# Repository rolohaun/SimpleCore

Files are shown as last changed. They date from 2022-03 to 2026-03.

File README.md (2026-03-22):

> [!WARNING]
> # 🚨 OUT OF DATE 🚨
> **This repository is out of date!** The updated printer is here: [SimpleCore on Printables](https://www.printables.com/model/1473500-simplecore)

---

# SimpleCore MK1
This is the official MK1 SimpleCore Github!

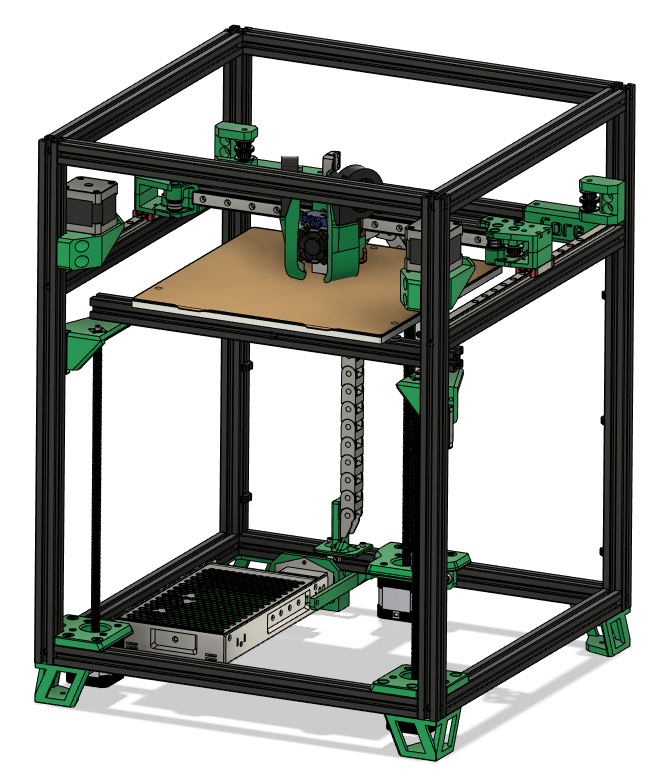
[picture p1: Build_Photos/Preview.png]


Features:

- Uses Voron Trident Frame
- Mantis Toolhead
- Triple Z motors
- Fully enclosable design
- Klicky Probe Support

BOM 250mm Size
https://docs.google.com/spreadsheets/d/1itUaLOwN8U-ldt7ZHBf0SfRjgWGmMog7KDNe5z_rCVY/edit#gid=0

My Patreon
https://www.patreon.com/rolohaun

Build Series
https://www.youtube.com/watch?v=_4NIc2eGpA0&list=PLypdl9fsWkKdIIs_hwjbh7VXXiUZjz-F_

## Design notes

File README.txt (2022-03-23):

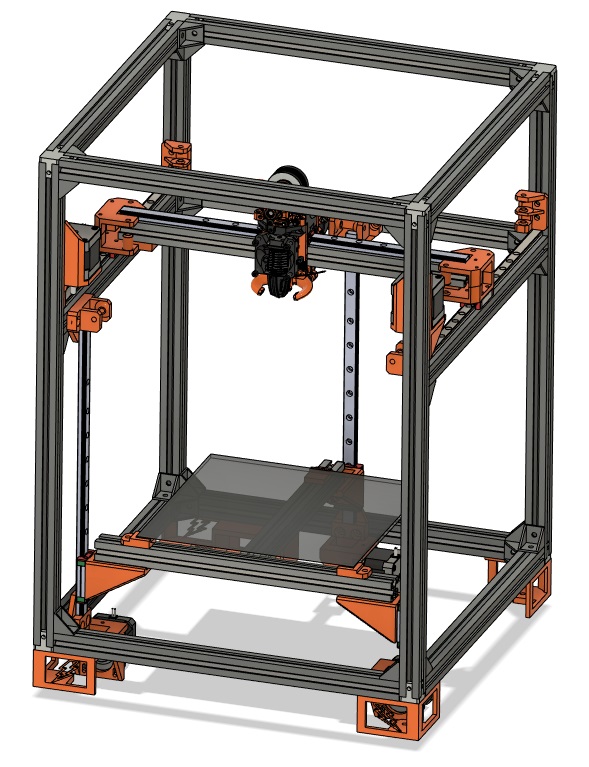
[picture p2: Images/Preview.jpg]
Title


Welcome to the DIY 3D Printer called SimpleCore!

PLEASE NOTE THIS PRINTER IS A WORK IN PROGRESS!

The goal of this printer is to make a very simple DIY corexy 3D printer than can be built by anyone for the cheapest possible.

Features:

- Simple 2020 Frame only 2 sizes needed, no drilling or taping
- EVA Toolhead support, build the printer you want
- Triple independant Z motors
- Fully enclosable design

BOM for 200x200 Build area (Work in progress!)
https://docs.google.com/spreadsheets/d/1O3hkrCF_OMRDucAhxMPro0IfUh7aCPbqEiQB7Yf0kRw/edit#gid=0

Find it on Youtube
https://www.youtube.com/watch?v=aPkX0bcwmN4

Support me on Patreon
https://www.patreon.com/rolohaun

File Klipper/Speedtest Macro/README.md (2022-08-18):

a macro that uses printer.cfg maximums for bed dimensions and feed rate maximums to move around fast

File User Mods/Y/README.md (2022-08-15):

Detect thin walls or similar slicer setting helps clean up idler towers

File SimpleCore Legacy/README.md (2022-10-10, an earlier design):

# SimpleCore Legacy
This is the old version of SimpleCore called legacy



PLEASE NOTE THIS A OLD VERSION! ( I am getting ready to release MK1 which will be the offical completed release )

The goal of this printer is to make a very simple DIY corexy 3D printer than can be built by anyone for the cheapest possible.

Features:

- Simple frame using standard size 2020 extrusions, no drilling or tapping
- EVA 2.4 Toolhead support, build the printer you want
- Triple belted Z motors
- Fully enclosable design
- Klicky Probe Support

BOM for SimpleCore Legacy ( Outdated Design )
https://docs.google.com/spreadsheets/d/1O3hkrCF_OMRDucAhxMPro0IfUh7aCPbqEiQB7Yf0kRw/edit#gid=0

My Discord
https://discord.gg/Dx3qwQN2DS

Find it on Youtube
https://www.youtube.com/watch?v=aPkX0bcwmN4

Support me on Patreon
https://www.patreon.com/rolohaun

EVA 2.4 Here
https://2.eva-3d.page/

Get Klicky Probe Here
https://github.com/jlas1/Klicky-Probe

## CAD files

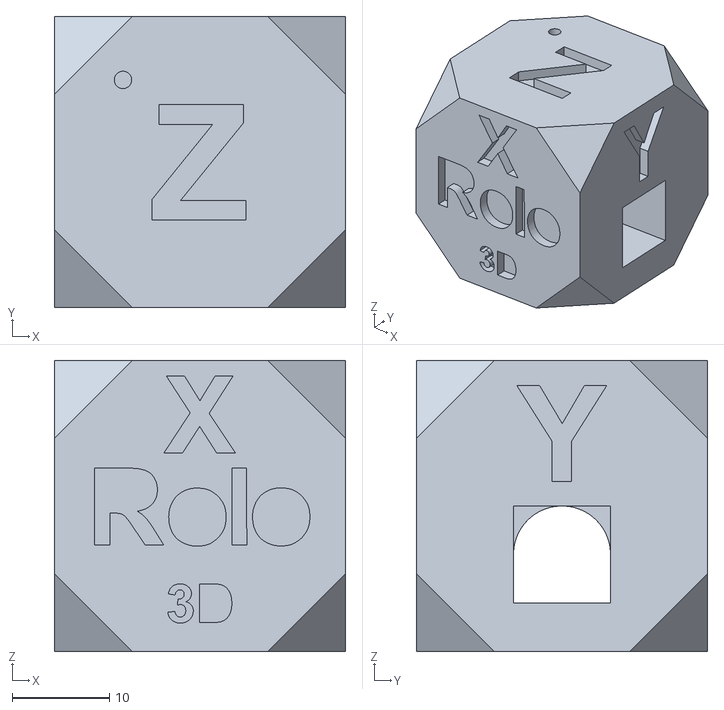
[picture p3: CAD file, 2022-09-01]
Calibration/Rolo_Cube.stl
30.0 x 30.0 x 30.0

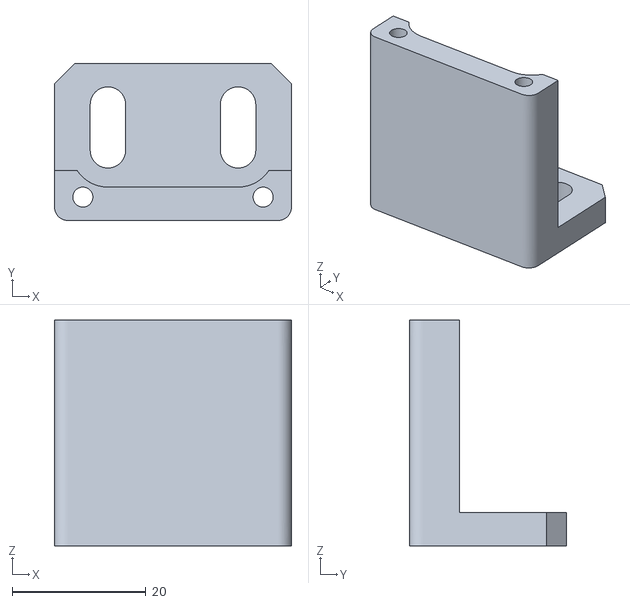
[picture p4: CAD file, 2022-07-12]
EVA 2.4 Klicky Dock/Klicky Dock EVA_2_4.stl
35.5 x 23.5 x 33.8

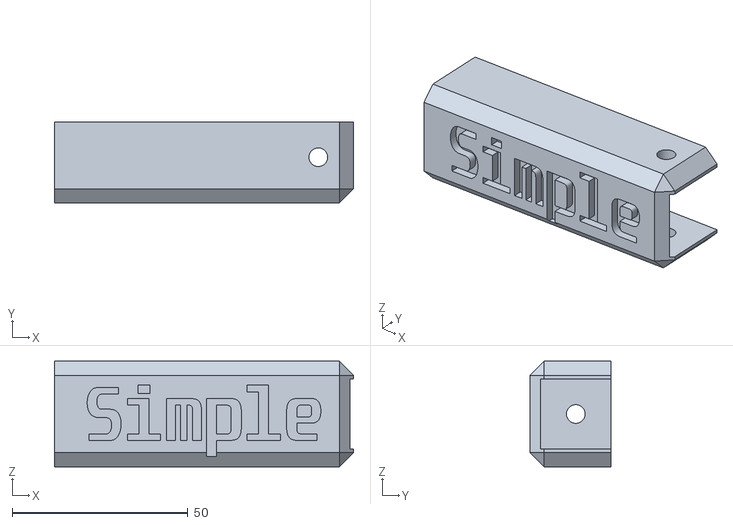
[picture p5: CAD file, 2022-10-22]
Frame/Rear_Brace_Left.stl
85.0 x 23.0 x 30.0

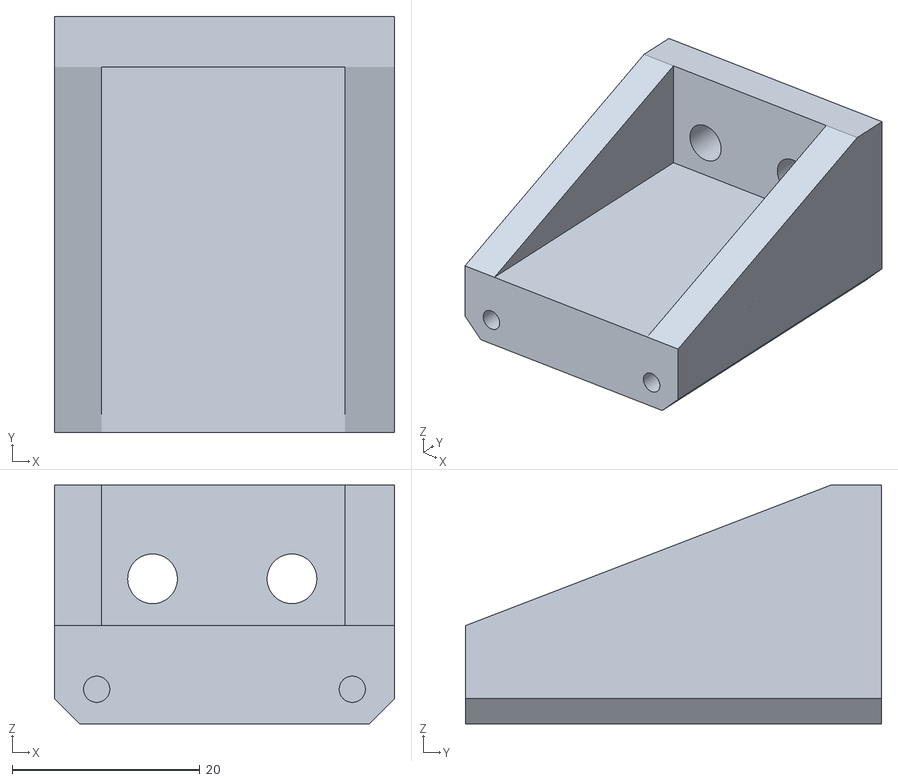
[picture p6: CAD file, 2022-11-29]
Klicky/Klicky_Frame_Dock.stl
36.3 x 44.4 x 25.5

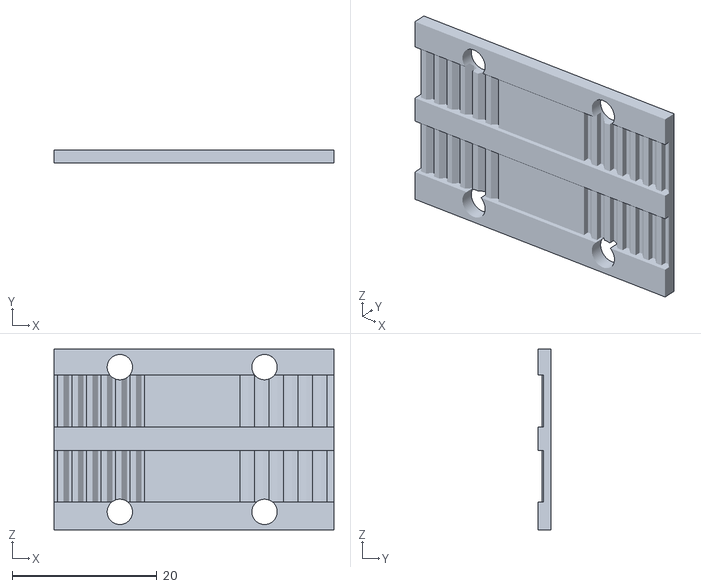
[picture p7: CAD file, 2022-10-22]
Mantis_Toolhead/Belt_Adapter.stl
38.7 x 1.75 x 25.0

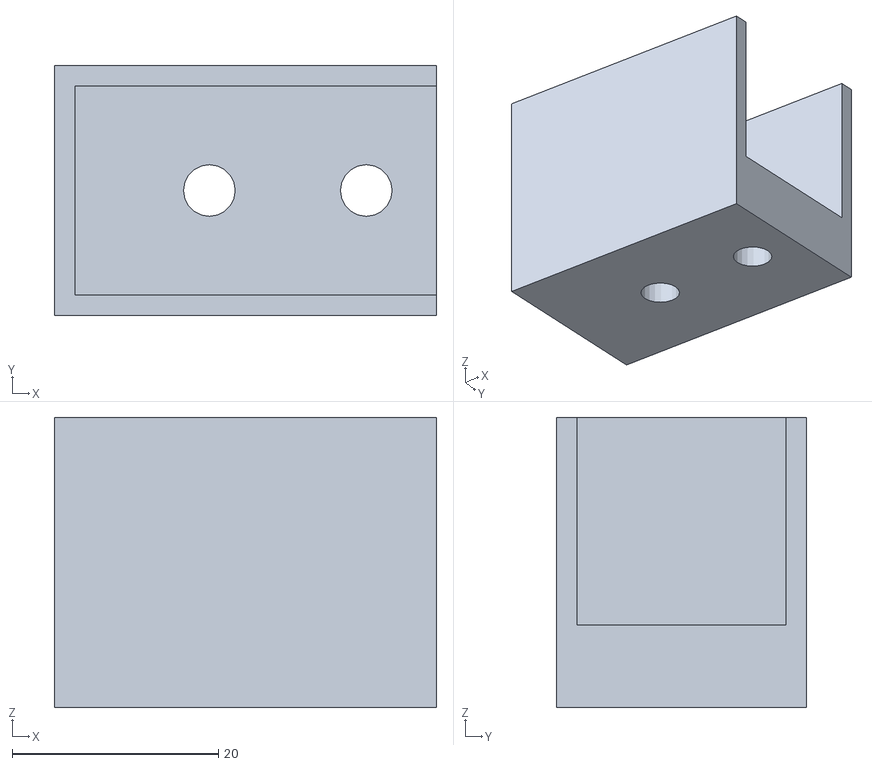
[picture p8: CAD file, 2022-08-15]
User Mods/CF Tube X Axis guides/5mm pilot hole guide-necessary.stl
37.0 x 24.2 x 28.1

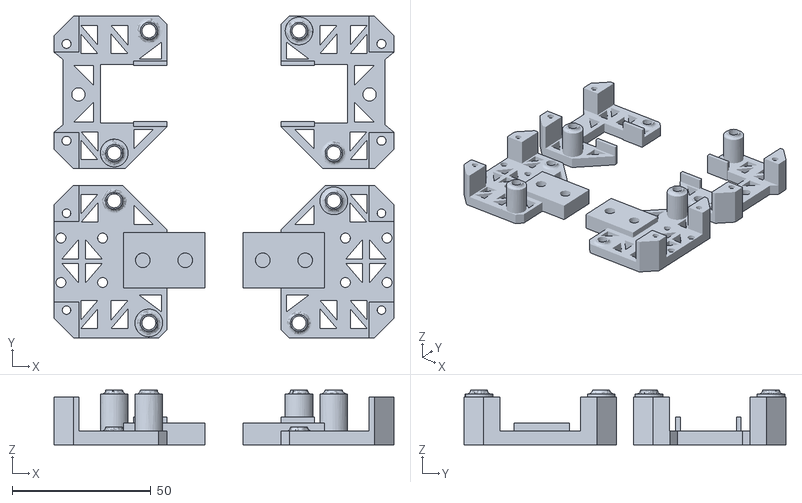
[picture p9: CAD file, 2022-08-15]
User Mods/Y/simplecore y carriage mod -fdm-v1.1.stl
122.4 x 115.9 x 19.8

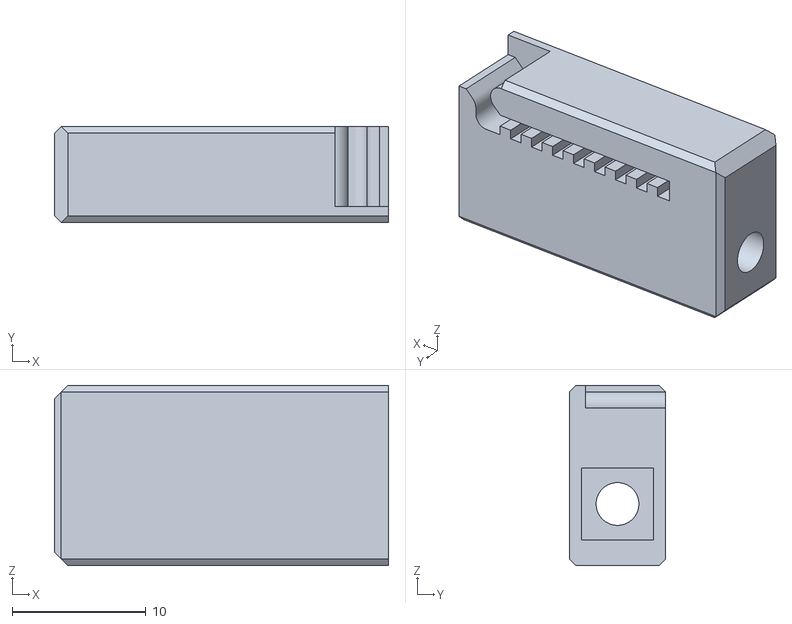
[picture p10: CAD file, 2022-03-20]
X/EVA Correct Belt Tensioner/tension sliders - tension_slider_6mm_belt_M3s_flip_mirror.stl
25.0 x 7.20 x 13.5

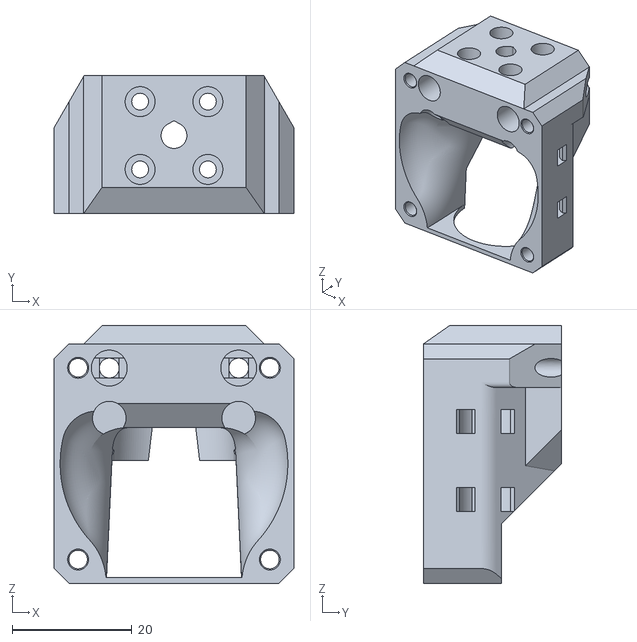
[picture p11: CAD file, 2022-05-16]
X/Phaetus_Klicky/lower_mount_phaetus.stl
40.0 x 23.0 x 43.1

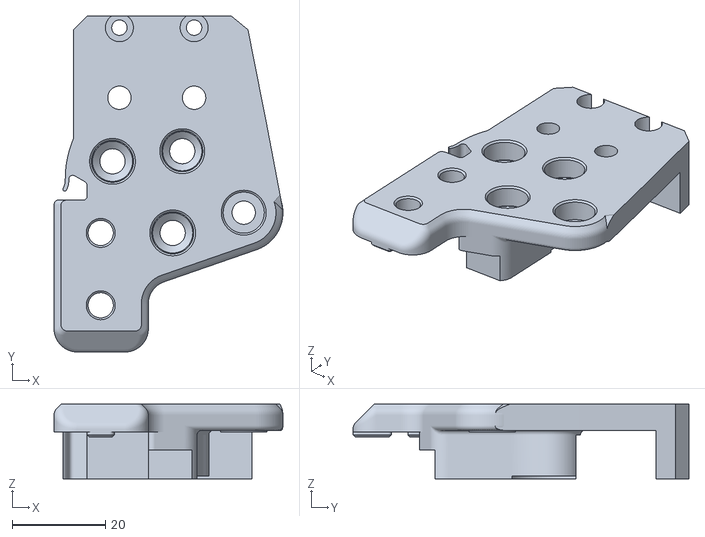
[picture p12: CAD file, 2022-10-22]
Y/Right_Y_Carriage_Top.stl
49.0 x 72.0 x 16.0

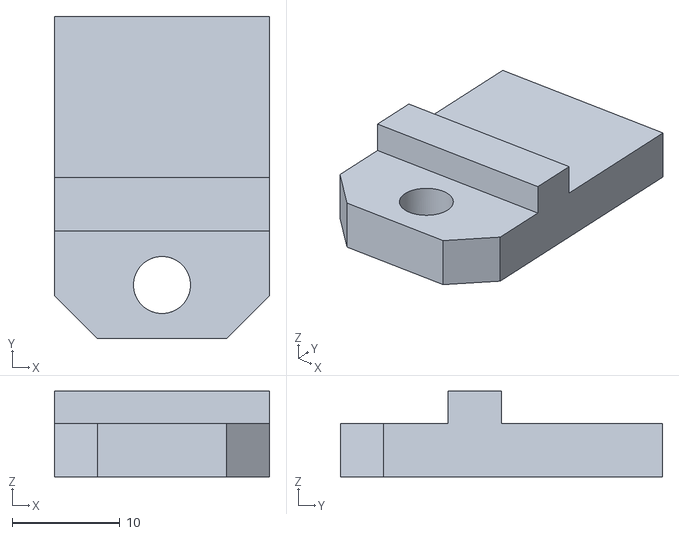
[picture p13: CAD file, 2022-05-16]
Z/330mm Bed/1 x 330_Bed_Mount Rear.stl
20.0 x 30.0 x 8.00

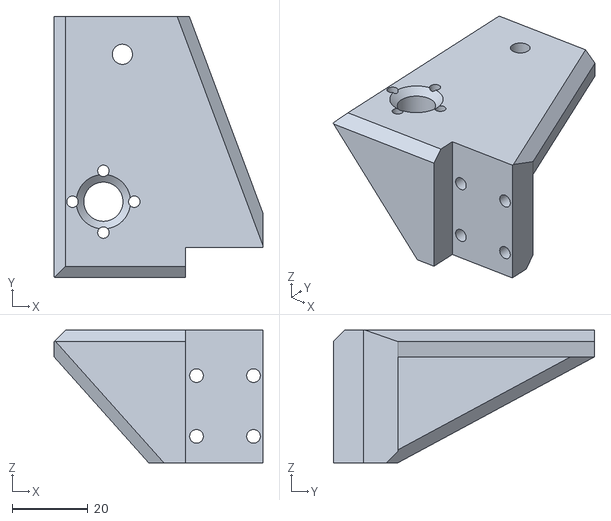
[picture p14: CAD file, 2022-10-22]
Z/Z_Bed_Mount_Right.stl
55.0 x 68.8 x 34.9

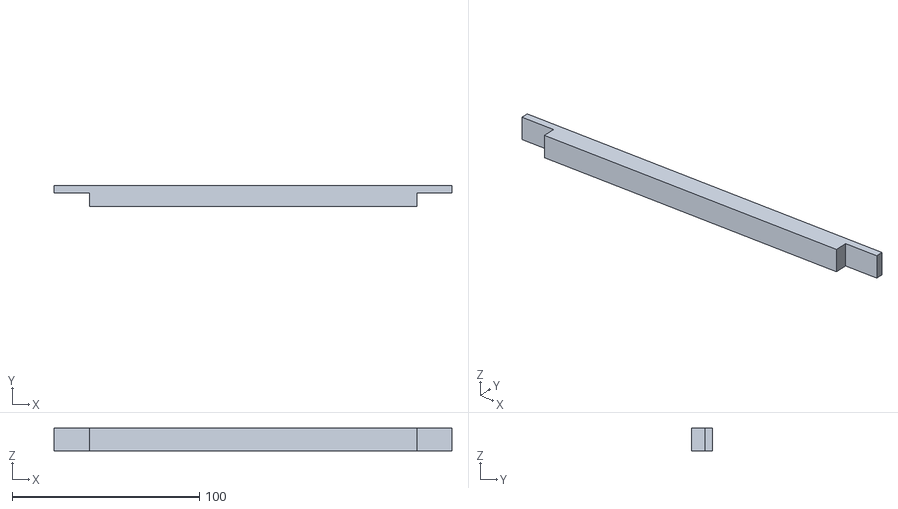
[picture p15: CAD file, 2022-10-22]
Frame/Rear_2020_aligment.stl
212.6 x 11.0 x 12.2

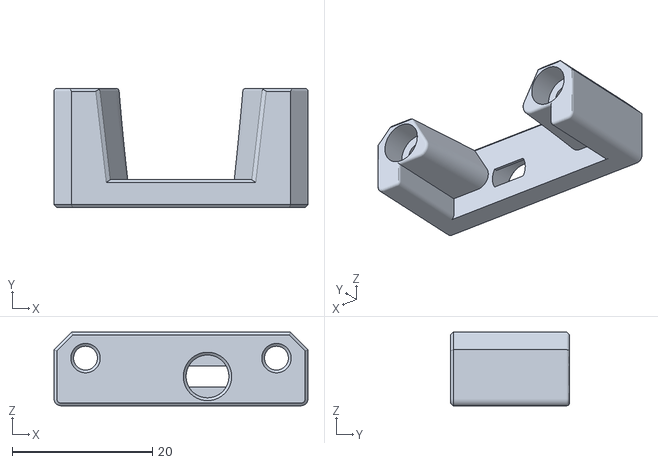
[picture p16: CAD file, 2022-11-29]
Klicky/Klicky_Dock.stl
36.3 x 17.0 x 10.5

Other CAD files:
Mantis_Toolhead/Left_Duct.stl
Y/Right_Y_Carriage_Bottom.stl
Z/330mm Bed/1 x 330_Bed_Mount Left.stl
Z/z_stepper_Mount_left.stl
CAD/Fusion360/SimpleCore_200.f3z
CAD/SimpleCore MK1.f3z
Frame/1 X A_Motor_Mount_MK1.stl
Frame/1 X B_Motor_Mount_MK1.stl
Frame/1 X Front_PSU_Mount.stl
Frame/1 X Left_Idler_Mount.stl
Frame/1 X Power_Inlet.stl
Frame/1 X Right_Idler_Mount.stl
Frame/4 X Foot_Mount.stl
Frame/Foot_Mount.stl
Frame/Guide_Tube_Mount.stl
Frame/Power_Inlet_Mount.stl
Frame/Rear_Brace_Right.stl
Frame/Rear_PSU_Mount.stl
Frame/Right_Idler_Mount.stl
Frame/Side_PSU_Mount.stl
Frame/bowen_retainer.stl
Frame/left_Idler_Mount.stl
Frame/spool_holder.stl
Mantis_Toolhead/Dragon_mount_sherpa.stl
Mantis_Toolhead/Right_Duct.stl
Mantis_Toolhead/X_hotend_mount_klicky.stl
SimpleCore Legacy/CAD/Fusion360/SimpleCore_200.f3z
SimpleCore Legacy/EVA 3 Belt Tensioners/EVA3__core_xy_belt_grabber_reverse.3mf
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

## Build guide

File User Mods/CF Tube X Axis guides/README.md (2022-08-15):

BOM:

1x 	20mm CF Tube cut to your front 2020 extrusion frame size
	EX. 350mm 2020 front of frame -> 350mm 20mm CF Tube

1x	MGN12H rail as in Normal BOM matching extrusion/cf tube Length

8+	M3 Nylock Nuts for mounting rail

4+	M5 nuts, Nylock or normal are usuable

Potential Weight savings: 

85g for a 350mm CF tube and 350mm MGN12h rail in comparison to normal BOM

Notes:

- It is highly recommended to square and trim your CF tube prior to cutting to length

- CF Tube dust is very dangerous to breath in please follow safety procedures when working with it

- CF tube length and rail can be scaled to large printer size by matching rail and cf tube to front
  2020 Extrusion size. Weight savings will vary if this method is taken

- Printed parts should be fine in PLA, PETG or ABS work well also

- Cf tube dril guides are made to rest on 3 sides of the tube and can be safely held while drilling

- Narrow rail guide is meant to wrap around the whole 20mm cf tube and a MGN12 Rail, 
  CF tubes vary in diameter by upto 0.3mm along corners this may make the guide tight reprint larger

- 350mm nut holder can be inserted from either side and is initially a bit large resize width as necessary

- Mounting of the rail doesn't need the nut holder if you drill through the opposite rail side to use a 5.5mm socket

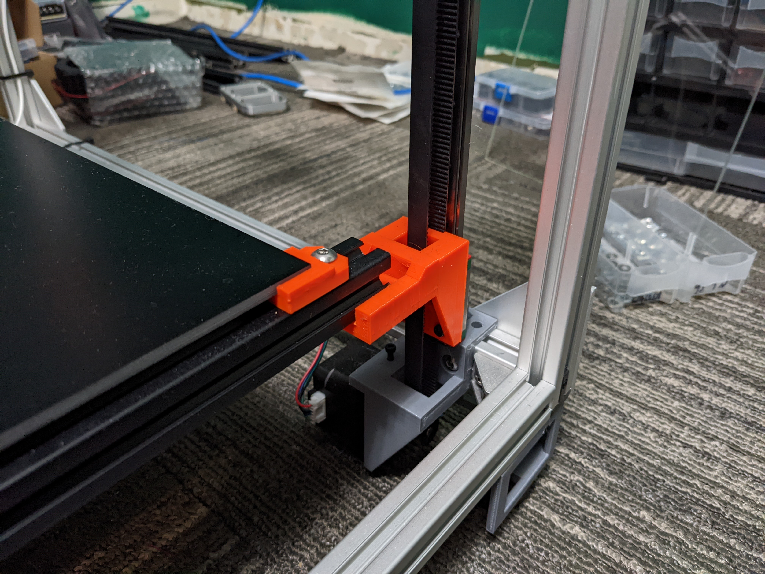
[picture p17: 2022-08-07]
Build_Photos/Front_Z_Mount.jpg

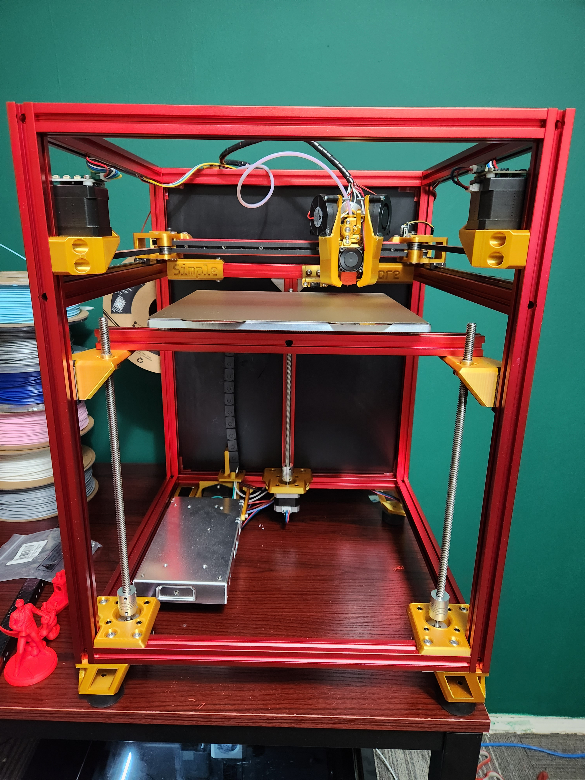
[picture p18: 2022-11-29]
Build_Photos/20221109_211722.jpg

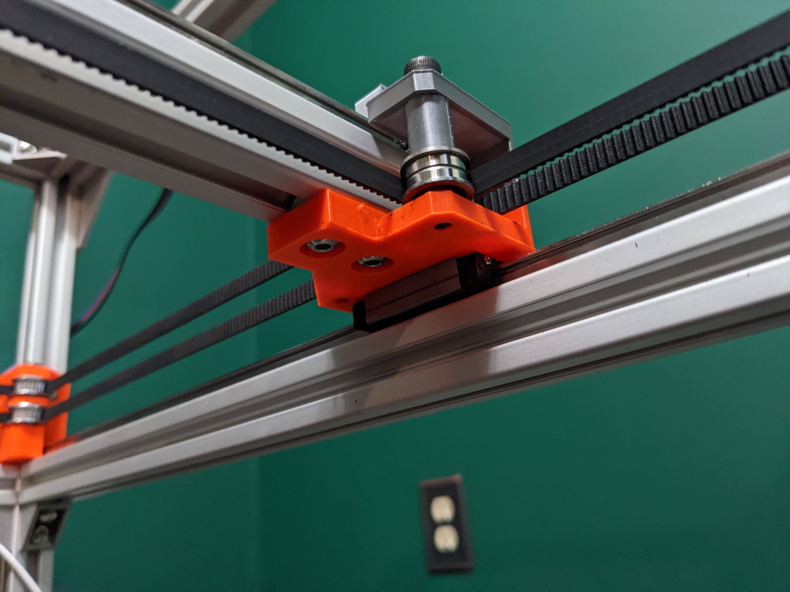
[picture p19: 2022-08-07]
Build_Photos/Y_Carriage_Botttom.jpg

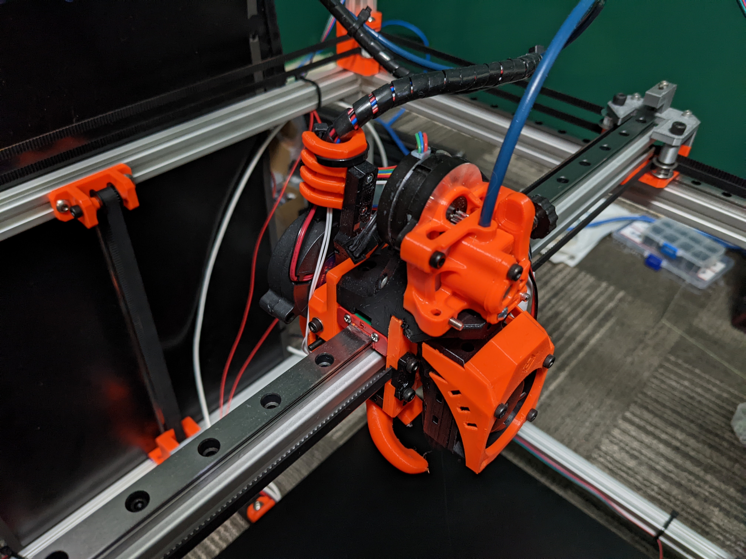
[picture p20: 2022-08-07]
Build_Photos/Eva 2.4.jpg

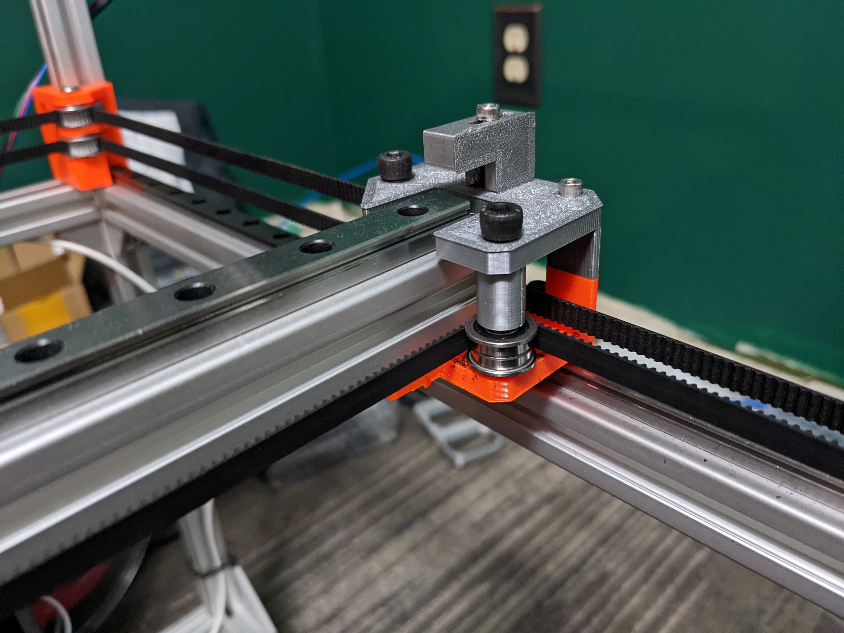
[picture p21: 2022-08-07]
Build_Photos/Y_Carriage.jpg

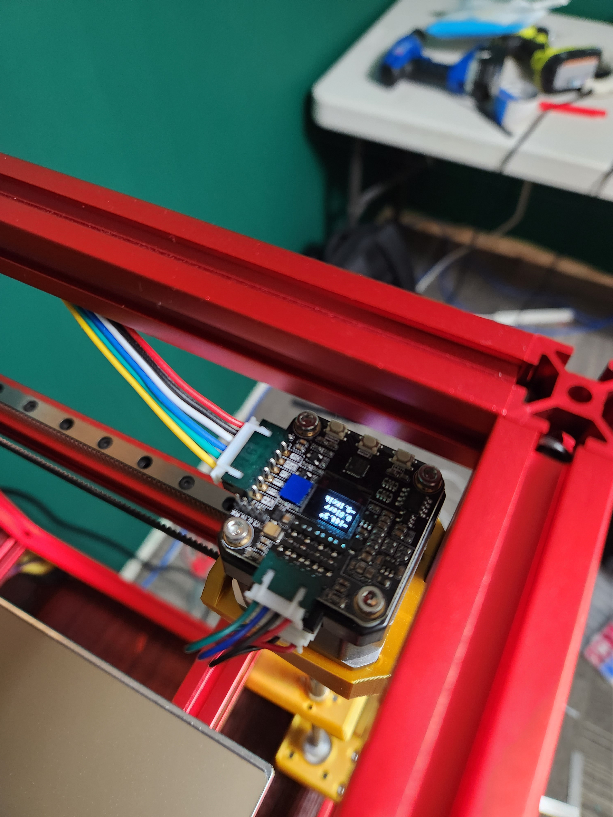
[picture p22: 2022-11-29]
Build_Photos/20221109_211734.jpg

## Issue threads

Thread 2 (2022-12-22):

Bom for 300, 350 frame builds.

firepower9966, 2022-12-22:
Can you add bom or list of changes needed for
300 and 350 size builds.
I assume its just size of linear rails and belt lengths.

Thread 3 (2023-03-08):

Belted Z version

rostrovsky, 2023-03-08:
Hi,

First off, thank you for sharing your designs. They are really great!

In video https://www.youtube.com/watch?v=HWfT2JbMOvM you were showing belted Z version of this printer. Are there any plans for releasing plans for it?

rostrovsky, 2023-03-08:
Ok I see that it's here: https://github.com/rolohaun/SimpleCore/tree/main/SimpleCore%20Legacy
🤦

Closed 2023-03-08.

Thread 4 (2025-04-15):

Broken Link in Legacy BOM Spreadsheet

chking999, 2025-04-15:
The link in the BOM spreadsheet for the SimpleCore Legacy doesn't work: Bambu Hotend ( Much cheaper use this mod https://www.printables.com/model/393230-eva-3-bambu-x1-hotend-adapter).  The parathesis at the end needs a space or it gets included in the link.

rolohaun, 2025-04-16:
Fixed

Closed 2025-04-16.

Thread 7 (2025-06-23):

Steppers underspecified in BoM and Aliexpress links are dead/blocked in the US

Ziraya, 2025-06-23:
I'm pricing out what this project would look like for me at the moment. Because of political conditions it would probably be cumbersome to order parts from AliExpress, which is fine, but for the NEMA17 and "300MM Lead Screw Integrated" steppers, I'm not able to determine what is called for

The Legacy BoM links to a NEMA17 1.8deg 0.42Nm with a 5x24mm D-shaft, likely the same? I think the most critical spec is torque, I can adapt the design for any other variation, but it needs a certain minimum torque to work as expected.

rolohaun, 2025-06-26:
Sorry for the delay, any voron Trident steppers will work here is a example

https://s.click.aliexpress.com/e/_olL7EME

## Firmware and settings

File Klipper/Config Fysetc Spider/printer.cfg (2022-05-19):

##[include adxl.cfg]
[include klicky-probe.cfg]

[gcode_macro PRINT_START]
#   Use PRINT_START for the slicer starting script - PLEASE CUSTOMISE THE SCRIPT
gcode:
    M117 Homing...                 ; display message
    G28
    Z_TILT_ADJUST


[gcode_macro PRINT_END]
#   Use PRINT_END for the slicer ending script - please customise for your slicer of choice
gcode:
    G1 Z220.2 F4000
    TURN_OFF_HEATERS
    G92 E0
    G1 E-2 F2500
    M107
    M84

[gcode_macro DOCK]
gcode:
    G1 Z220.2 F4000

[temperature_sensor mcu_temp]
sensor_type: temperature_mcu
min_temp: 0
max_temp: 100

[virtual_sdcard]
path: ~/gcode_files

[display_status]

[pause_resume]

[gcode_macro PAUSE]
description: Pause the actual running print
rename_existing: PAUSE_BASE
gcode:
    ##### set defaults #####
    {% set x = params.X|default(120) %}      #edit to your park position
    {% set y = params.Y|default(120) %}      #edit to your park position
    {% set z = params.Z|default(10)|float %} #edit to your park position
    {% set e = params.E|default(1) %}        #edit to your retract length
    ##### calculate save lift position #####
    {% set max_z = printer.toolhead.axis_maximum.z|float %}
    {% set act_z = printer.toolhead.position.z|float %}
    {% set lift_z = z|abs %}
    {% if act_z < (max_z - lift_z) %}
        {% set z_safe = lift_z %}
    {% else %}
        {% set z_safe = max_z - act_z %}
    {% endif %}
    ##### end of definitions #####
    PAUSE_BASE
    G91
    {% if printer.extruder.can_extrude|lower == 'true' %}
      G1 E-{e} F2100
    {% else %}
      {action_respond_info("Extruder not hot enough")}
    {% endif %}
    {% if "xyz" in printer.toolhead.homed_axes %}    
      G1 Z{z_safe}
      G90
      G1 X{x} Y{y} F6000
    {% else %}
      {action_respond_info("Printer not homed")}
    {% endif %}

[gcode_macro RESUME]
description: Resume the actual running print
rename_existing: RESUME_BASE
gcode:
    ##### set defaults #####
    {% set e = params.E|default(1) %} #edit to your retract length
    #### get VELOCITY parameter if specified ####
    {% if 'VELOCITY' in params|upper %}
      {% set get_params = ('VELOCITY=' + params.VELOCITY)  %}
    {%else %}
      {% set get_params = "" %}
    {% endif %}
    ##### end of definitions #####
    G91
    {% if printer.extruder.can_extrude|lower == 'true' %}
      G1 E{e} F2100
    {% else %}
      {action_respond_info("Extruder not hot enough")}
    {% endif %}  
    RESUME_BASE {get_params}

[gcode_macro CANCEL_PRINT]
description: Cancel the actual running print
rename_existing: CANCEL_PRINT_BASE
gcode:
    TURN_OFF_HEATERS
    CANCEL_PRINT_BASE

# B MOTOR LEFT
[stepper_x]
step_pin: PE11
dir_pin: !PE10
enable_pin: !PE9
microsteps: 32
rotation_distance: 40
endstop_pin: !PA1
position_endstop: 360
position_max: 360
homing_speed: 50 

[tmc2209 stepper_x]
uart_pin: PE7
#interpolate: False
run_current: 0.7
#sense_resistor: 0.110
stealthchop_threshold: 999999

# A MOTOR RIGHT
[stepper_y]
step_pin: PD8
dir_pin: !PB12
enable_pin: !PD9
microsteps: 32
rotation_distance: 40
endstop_pin: !PA2  # PA2 for Y-max
position_endstop: 380
position_max: 380
homing_speed: 50 

[tmc2209 stepper_y]
uart_pin: PE15
#interpolate: False
run_current: 0.7
#sense_resistor: 0.110
stealthchop_threshold: 999999

# FRONT LEFT STEPPER
[stepper_z]
step_pin: PD14
dir_pin: !PD13
enable_pin: !PD15
microsteps: 32
rotation_distance: 40
endstop_pin: probe:z_virtual_endstop
#endstop_pin: PA0  # PA3 for Z-max
#position_endstop: 0
position_max: 250
position_min: -10
homing_speed: 20

[tmc2209 stepper_z]
uart_pin: PD10
#interpolate: False
run_current: 0.6
#sense_resistor: 0.110
stealthchop_threshold: 999999

# REAR CENTER STEPPER
[stepper_z1]
step_pin: PE6
dir_pin: !PC13
enable_pin: !PE5
microsteps: 32
rotation_distance: 40
endstop_pin: probe:z_virtual_endstop
#endstop_pin: PA0  # PA3 for Z-max
#position_endstop: 0
#position_max: 250

[tmc2209 stepper_z1]
uart_pin: PC14
#interpolate: False
run_current: 0.6
#sense_resistor: 0.110
stealthchop_threshold: 999999

# Front Right Z STEPPER
[stepper_z2]
step_pin: PE2
dir_pin: PE4
enable_pin: !PE3
microsteps: 32
rotation_distance: 40
endstop_pin: probe:z_virtual_endstop
#endstop_pin: PA0  # PA3 for Z-max
#position_endstop: 0
#position_max: 250

[tmc2209 stepper_z2]
uart_pin: PC15
#interpolate: False
run_current: 0.6
#sense_resistor: 0.110
stealthchop_threshold: 999999

[extruder]
step_pin: PD5
dir_pin: PD6
enable_pin: !PD4

##	Update value below when you perform extruder calibration
##	If you ask for 100mm of filament, but in reality it is 98mm:
##	rotation_distance = <previous_rotation_distance> * <actual_extrude_distance> / 100
##  22.6789511 is a good starting point for Bondtech 5mm gears
##  34.37086 for Bondtech 8mm gears (Galileo)
rotation_distance: 21.33852984	#Bondtech 5mm Drive Gears
##	Update Gear Ratio depending on your Extruder Type
##	Use 50:17 for Afterburner/Clockwork (BMG Gear Ratio)
##	Use 80:20 for M4, M3.1
##  Use 7.5:1 for Galileo
gear_ratio: 50:10				#BMG Gear Ratio
microsteps: 32
#full_steps_per_rotation: 200	#200 for 1.8 degree, 400 for 0.9 degree
nozzle_diameter: 0.400
filament_diameter: 1.75
##      In E0 OUT Position
heater_pin: PB15
##	Validate the following thermistor type to make sure it is correct
sensor_type: ATC Semitec 104NT-4-R025H42G
sensor_pin: PC0
min_temp: 10
max_temp: 270
max_power: 1.0
min_extrude_temp: 170
#control = pid
#pid_kp = 26.213
#pid_ki = 1.304
#pid_kd = 131.721
##	Try to keep pressure_advance below 1.0
pressure_advance: 0.06
##	Default is 0.040, leave stock
pressure_advance_smooth_time: 0.040

[tmc2209 extruder]
uart_pin: PD7
#interpolate: False
run_current: 0.25
#sense_resistor: 0.110
stealthchop_threshold: 999999

[probe]
##	If your probe is NO instead of NC, change pin to ^!PA3
pin: ^PA0
x_offset: 45
y_offset: 0
z_offset: 5.2
speed: 5
samples: 3
samples_result: median
sample_retract_dist: 3.0
samples_tolerance: 0.01
samples_tolerance_retries: 3

#[safe_z_home]
#home_xy_position: 165, 165 # Change coordinates to the center of your print bed
#speed: 100
#z_hop: 0                 # Move up 10mm
#z_hop_speed: 5

[z_tilt]
horizontal_move_z: 10
##200mm build
z_positions:
    15, 0
    165, 400
    315, 0
points:
    15, 15
    165, 265
    315, 15
speed: 100
horizontal_move_z: 10
retries: 5
retry_tolerance: 0.015

#[heater_bed]
#heater_pin: PB4
#sensor_type: NTC 100K MGB18-104F39050L32
#sensor_pin: PC3
#max_power: 0.6
#control: pid
#pid_Kp: 54.027
#pid_Ki: 0.770
#pid_Kd: 948.182
#min_temp: 0
#max_temp: 130

[heater_fan hotend_fan]
##	Hotend Fan - FAN0 Connector
pin: PB0
max_power: 1.0
#kick_start_time: 0.5
heater: extruder
heater_temp: 50.0
##	If you are experiencing back flow, you can reduce fan_speed
#fan_speed: 1.0

[fan]
##	Print Cooling Fan - FAN1 Connector
pin: PB1
#max_power: 1.0
#kick_start_time: 0.5
##	Depending on your fan, you may need to increase this value
##	if your fan will not start. Can change cycle_time (increase)
##	if your fan is not able to slow down effectively
off_below: 0.10

#fan for control board FAN2
#[heater_fan my_control_fan]
#pin: PB2

#####################################################################
# LED Control
#####################################################################

#[output_pin caselight ]
##  Chamber Lighting - In 5V-RGB Position
#pin: PD3
#pwm: true
#shutdown_value: 0
#value:100
#cycle_time: 0.01

[mcu]
## Obtain definition by "ls -l /dev/serial/by-id/" then unplug to verify
serial: /dev/serial/by-id/usb-Klipper_stm32f446xx_1E0014001050563046363120-if00

[printer]
kinematics: corexy
max_velocity: 220
max_accel: 2200      #Max 4000
max_z_velocity: 15			#Max 15 for 12V TMC Drivers, can increase for 24V
max_z_accel: 100
square_corner_velocity: 5.0

########################################
# EXP1 / EXP2 (display) pins
########################################

[board_pins]
aliases:
    # EXP2 header
    EXP1_10=<5V>, EXP1_9=<GND>,
    EXP1_8=PD1,   EXP1_7=PD0,
    EXP1_6=PC12,  EXP1_5=PC10,     # Slot in the socket on the other side
    EXP1_4=PD2,   EXP1_3=PC11,
    EXP1_2=PA8,   EXP1_1=PC9,

    # EXP1 header
    EXP2_10=<5V>, EXP2_9=<GND>,
    EXP2_8=<RST>, EXP2_7=PB10,
    EXP2_6=PA7,   EXP2_5=PC7,       # Slot in the socket on the other side
    EXP2_4=PA4,   EXP2_3=PC6,
    EXP2_2=PA5,   EXP2_1=PA6

# See the sample-lcd.cfg file for definitions of common LCD displays.

#*# <---------------------- SAVE_CONFIG ---------------------->
#*# DO NOT EDIT THIS BLOCK OR BELOW. The contents are auto-generated.
#*#
#*# [extruder]
#*# control = pid
#*# pid_kp = 19.022
#*# pid_ki = 1.307
#*# pid_kd = 69.192
#*#
#*# [probe]
#*#
#*# [input_shaper]
#*# shaper_type_x = 2hump_ei
#*# shaper_freq_x = 42.6
#*# shaper_type_y = zv
#*# shaper_freq_y = 26.0

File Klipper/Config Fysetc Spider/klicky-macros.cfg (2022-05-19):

# This macro was provided by discord user Garrettwp to whom i give my thanks for sharing it with me.
# I have tweaked it a lot.
# They are based on the great Annex magprobe dockable probe macros "#Originally developed by Mental,
# modified for better use on K-series printers by RyanG and Trails", kudos to them.
# That macro as since evolved into a klipper plugin that currently is pending inclusion in klipper, 
# more information here, https://github.com/Annex-Engineering/Quickdraw_Probe/tree/main/Klipper_Macros
# User richardjm revised the macro variables and added some functions, thanks a lot
# by standing on the shoulders of giants, lets see if we can see further
#
# the current home for this version is https://github.com/jlas1/Klicky-Probe 

[respond]

[gcode_macro _Probe_Variables]
variable_probe_attached:            False
variable_probe_state:               False
variable_probe_lock:                False
variable_z_endstop_x:               0
variable_z_endstop_y:               0
gcode:


#checks if the variable definitions are up to date
[gcode_macro _klicky_check_variables_version]
gcode:
    {% set version = printer["gcode_macro _User_Variables"].version|default(0) %}

    {% if version != 1 %}
        { action_raise_error("Please update your klicky variables, there are some functionality changes") }
    {% endif %}

[gcode_macro _exit_point]
gcode:
    {% set function  = 'pre_' ~ params.FUNCTION %}
    {% set move  = params.MOVE|default(0) %}
    {% set speed = params.SPEED|default(printer["gcode_macro _User_Variables"].travel_speed) %}
    # mandatory to save the new safe position
    M400
    SET_VELOCITY_LIMIT ACCEL={printer.configfile.settings.printer.max_accel}
    SET_VELOCITY_LIMIT ACCEL_TO_DECEL={printer.configfile.settings.printer.max_accel_to_decel}
    RESTORE_GCODE_STATE NAME={function} MOVE={move} MOVE_SPEED={speed}


[gcode_macro _entry_point]
gcode:
    {% set function  = 'pre_' ~ params.FUNCTION %}
    {% set move_accel = printer["gcode_macro _User_Variables"].move_accel|default(1000) %}
    # mandatory to save the new safe position
    M400
    SAVE_GCODE_STATE NAME={function}
    # removes the Z offset for better bed based docking
    SET_GCODE_OFFSET Z=0
    # all the macros initially assume absolute positioning
    G90
    # set a safe(sane) Acceleration
    SET_VELOCITY_LIMIT ACCEL={move_accel}

[gcode_macro _Homing_Variables]
gcode:
    {% set reset  = params.RESET|default(0) %}
    {% if reset %}
        SET_GCODE_VARIABLE MACRO=_Probe_Variables VARIABLE=probe_lock VALUE={ False }
    {% endif %}

##########################
# Attach probe and lock it
[gcode_macro Attach_Probe_Lock]
description: Attaches Klicky Probe, can only be docked after unlocking
gcode:
    Attach_Probe
    _Probe_Lock

########################
# Dock probe and lock it
[gcode_macro Dock_Probe_Unlock]
description: Docks Klicky Probe even if it was locked
gcode:
    _Probe_Unlock
    Dock_Probe

##############
# Unlock Probe
[gcode_macro _Probe_Unlock]
description: Unlocks Klicky Probe state
gcode:
    SET_GCODE_VARIABLE MACRO=_Probe_Variables VARIABLE=probe_lock VALUE={ False }

############
# Lock Probe
[gcode_macro _Probe_Lock]
description: Locks Klicky Probe state
gcode:
    SET_GCODE_VARIABLE MACRO=_Probe_Variables VARIABLE=probe_lock VALUE={ True }

######################
# Attach Probe Routine
[gcode_macro Attach_Probe]
description: Attaches Klicky Probe
gcode:
    # See if the position should be restored after the attach
    {% set goback  = params.BACK|default(0) %}
    # Get probe attach status
    {% set probe_attached = printer["gcode_macro _Probe_Variables"].probe_attached %}
    {% set probe_lock = printer["gcode_macro _Probe_Variables"].probe_lock %}
    {% set verbose = printer["gcode_macro _User_Variables"].verbose %}
    # Get Docking location
    {% set dockmove_x = printer["gcode_macro _User_Variables"].dockmove_x|default(0) %}
    {% set dockmove_y = printer["gcode_macro _User_Variables"].dockmove_y|default(0) %}
    {% set dockmove_z = printer["gcode_macro _User_Variables"].dockmove_z|default(0) %}
    {% set docklocation_x = printer["gcode_macro _User_Variables"].docklocation_x %}
    {% set docklocation_y = printer["gcode_macro _User_Variables"].docklocation_y %}
    {% set docklocation_z = printer["gcode_macro _User_Variables"].docklocation_z %}
    {% set attachmove_x = printer["gcode_macro _User_Variables"].attachmove_x|default(0) %}
    {% set attachmove_y = printer["gcode_macro _User_Variables"].attachmove_y|default(0) %}
    {% set attachmove_z = printer["gcode_macro _User_Variables"].attachmove_z|default(0) %}
    {% set attachmove2_x = printer["gcode_macro _User_Variables"].attachmove2_x|default(0) %}
    {% set attachmove2_y = printer["gcode_macro _User_Variables"].attachmove2_y|default(0) %}
    {% set attachmove2_z = printer["gcode_macro _User_Variables"].attachmove2_z|default(0) %}
    # Safe Z for travel
	{% set safe_z = 0 %}
	{% set enable_z_hop = printer["gcode_macro _User_Variables"].enable_z_hop %}
    # Set feedrates
    {% set travel_feedrate = printer["gcode_macro _User_Variables"].travel_speed * 60 %}
    {% set dock_feedrate = printer["gcode_macro _User_Variables"].dock_speed * 60 %}
    {% set release_feedrate = printer["gcode_macro _User_Variables"].release_speed * 60 %}
    {% set z_drop_feedrate = printer["gcode_macro _User_Variables"].z_drop_speed * 60 %}

    _entry_point function=Attach_Probe

    # If there is no undock movement, fail
    {% if dockmove_x == dockmove_y == dockmove_z == 0 %}
        { action_raise_error("No dockmove location!! To restore old behavior place 40 in dockmove_x") }
    {% endif %}
    # If there is no Attach movement, fail
    {% if attachmove_x == attachmove_y == attachmove_z == 0 %}
        { action_raise_error("No attachmove location!!  To restore old behavior place dockarmslenght value in dockmove_x") }
    {% endif %}

    # If x and y are not homed
    {% if not 'xy' in printer.toolhead.homed_axes %}
        { action_raise_error("Must Home X and Y Axis First!") }

    # If probe not attached and locked
    {% elif not probe_attached and not probe_lock %}
        {% if verbose %}
            { action_respond_info("Attaching Probe") }
        {% endif %}

        {% if not 'z' in printer.toolhead.homed_axes %}
            {% if verbose %}
                { action_respond_info("Resetting Z position to zero") }
            {% endif %}
            SET_KINEMATIC_POSITION Z=0
            {% if not enable_z_hop %} # Disables safe_z
                {% set safe_z = 0 %}
            {% endif %}
        {% endif %}

        # Prior to saving actual position, check if its necessary to move to a safe Z
        # that has enought overhead for the attached probe
        {% if printer.toolhead.position.z < safe_z %}
            {% if verbose %}
                { action_respond_info("moving to a safe Z distance") }
            {% endif %}
            G0 Z{safe_z} F{z_drop_feedrate}
        {% endif %}

        {% if not 'z' in printer.toolhead.homed_axes %}
            {% if verbose %}
                { action_respond_info("Resetting Z position to zero") }
            {% endif %}
            SET_KINEMATIC_POSITION Z=0
        {% endif %}

        {% if printer.toolhead.position.z < safe_z %}
            G0 Z{safe_z} F{z_drop_feedrate}
        {% endif %}

        _Umbilical_Path

        _entry_point function=Attach_Probe_intern

        # if necessary do some actions before moving the toolhead to the docking position
        {% if printer["gcode_macro _DeployDock"] is defined %}
            _DeployDock
        {% endif %}

        # Probe entry location
        G0 X{docklocation_x|int - attachmove_x|int - attachmove2_x|int} Y{docklocation_y|int - attachmove_y|int - attachmove2_y} F{travel_feedrate}
        {% if docklocation_z != -128 %}
            G0 Z{docklocation_z|int - attachmove_z|int - attachmove2_z|int} F{dock_feedrate}
			G0 Z{docklocation_z|int - attachmove_z|int} F{dock_feedrate}
        {% endif %}

        # Drop Probe to Probe location
        {% if docklocation_z != -128 %}
            G0 Z{docklocation_z} F{dock_feedrate}
        {% endif %}
		G0 X{docklocation_x|int - attachmove2_x|int} Y{docklocation_y|int - attachmove2_y} F{travel_feedrate}
        G0 X{docklocation_x} Y{docklocation_y} F{dock_feedrate}

        # Probe Attach
        {% if docklocation_z != -128 %}
        G0 Z{docklocation_z|int - attachmove_z|int} F{z_drop_feedrate}
        {% endif %}
        G0 X{docklocation_x|int - attachmove_x|int} Y{docklocation_y|int - attachmove_y|int} F{release_feedrate}

        # if necessary do some actions after attaching the probe
        {% if printer["gcode_macro _RetractDock"] is defined %}
            _RetractDock
        {% endif %}
		
        # Go to Z safe distance
        {% if printer.toolhead.position.z < safe_z %}
          G0 Z{safe_z} F{z_drop_feedrate}
        {% endif %}

        _Park_Toolhead
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

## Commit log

2022-03-20 DIY 3D Printer Called SimpleCore
    Welcome to the SimpleCore CoreXY 3D printer
    [A_Motor_Mount.stl, B_Motor_Mount.stl, Endstop_slide.stl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]
2022-05-16 300mm and MGN9 update
    [1 X 300mm Z_Rear_Center_Bed_Ledge (2).stl, 1 X Left_Idler_Mount.stl, 1 X Right_Idler_Mount.stl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]
2022-05-16 300mm build organization
    [1 X 300mm Z_Rear_Center_Bed_Ledge (2).stl, 1 x 330_Bed_Mount Left.stl, 1 x 330_Bed_Mount Rear.stl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]
2022-05-19 Klicky Config Update
    [Klicky Dock.stl, adxl.cfg, klicky-bed-mesh-calibrate.cfg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]
2022-05-22 Idler update
    [1 X Left_Idler_Mount.stl, 1 X Right_Idler_Mount.stl]
2022-05-29 Z Part Revision
    [1 X Front_Left_Z_Motor_Mount.stl, 1 X Front_Right_Z_Motor_Mount.stl, 1 X Z_Linear_Rail_Top_Mount.stl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]
2022-07-22 Update 1 X Power_Inlet.stl
    [1 X Power_Inlet.stl]
2022-07-24 Mod by militaryman_20
    [simplecore_y_carriage_mod-FDM_version.stl]
2022-07-24 Update SimpleCore 200 CAD by ZombieHedgehog
2022-07-24 LFS and User Mods
    [SimpleCore 200.f3d]
2022-08-09 new z bed mount for 330 size SimpleCore
    [3 X Z_Bed_Mount_MG9_MG12_V2.stl]
2022-08-10 Updated CAD with the help of ZombieHedgehog
    [SimpleCore_200.f3z]
2022-08-15 Mods by militaryman_20
    [2mm pilot hole guide optional.stl, 350mm mgn12 4 hole nut holder x2.stl, 5mm pilot hole guide-necessary.stl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]
2022-08-15 Updated Motor Mounts
    [1 X A_Motor_Mount.stl, 1 X B_Motor_Mount.stl]
2022-08-15 Motor Mount Update
    [1 X A_Motor_Mount.stl, 1 X B_Motor_Mount.stl]
2022-08-18 Speed Test Macro
    [speedtestxy.cfg]
2022-08-22 MGN12H only supported
    [3 X Z_Bed_Mount_MG12H.stl, 3 X Z_Bed_Mount_MG9_MG12_V2.stl]
2022-08-24 MK1 Release
    [1 X A_Motor_Mount.stl, 1 X A_Motor_Mount_MK1.stl, 1 X B_Motor_Mount.stl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]
2022-09-06 Create Klicky Dock EVA_2_4.stl
    [Klicky Dock EVA_2_4.stl]
2022-10-10 MK1 Update
    [1 X Front_PSU_Mount.stl, 1 X Power_Inlet.stl, 4 X Foot_Mount.stl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]
2022-10-22 change
    MK1 CAD
    MK1 CAD
    Delete SimpleCore MK1.f3z
    Create SimpleCore MK1.f3z
